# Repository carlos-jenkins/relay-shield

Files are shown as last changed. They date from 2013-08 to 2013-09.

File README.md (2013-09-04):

Advanced Relay Shield for Spark Core
====================================

[Spark Core] [] is a open source hardware Arduino compatible tiny Wi-Fi
development board that makes it easy to create internet-connected hardware.
This shield allows the Spark Core to control a high-power AC device and sense
the current flow.

Features
--------

  - Rated up to 220VAC @ 20A (4400W) ([part] [1]).
  - Current sensing using a CT sensor ([part] [2]).
  - Manual switch.
  - Panel/box ready.

Schematic
---------

Schematic

[Schematic in PDF] [].

PCB
---

PCB

[PCB on OSHPark] [].

License
-------

Copyright (C) 2013 Carlos Jenkins <carlos@jenkins.co.cr>

This program is free software; you can redistribute it and/or modify
it under the terms of the GNU General Public License as published by
the Free Software Foundation; either version 2 of the License, or
(at your option) any later version.

This program is distributed in the hope that it will be useful,
but WITHOUT ANY WARRANTY; without even the implied warranty of
MERCHANTABILITY or FITNESS FOR A PARTICULAR PURPOSE.  See the
GNU General Public License for more details.

You should have received a copy of the GNU General Public License
along with this program.  If not, see <http://www.gnu.org/licenses/>.

  [1]: https://www.sparkfun.com/products/10924
  [2]: https://www.sparkfun.com/products/11005
  [Spark Core]: https://www.sparkdevices.com/
  [Schematic in PDF]: https://github.com/carlos-jenkins/relay-shield/raw/master/board/schematic/v1.0/relay_shield.pdf
  [PCB on OSHPark]: http://oshpark.com/shared_projects/E1XSjK44

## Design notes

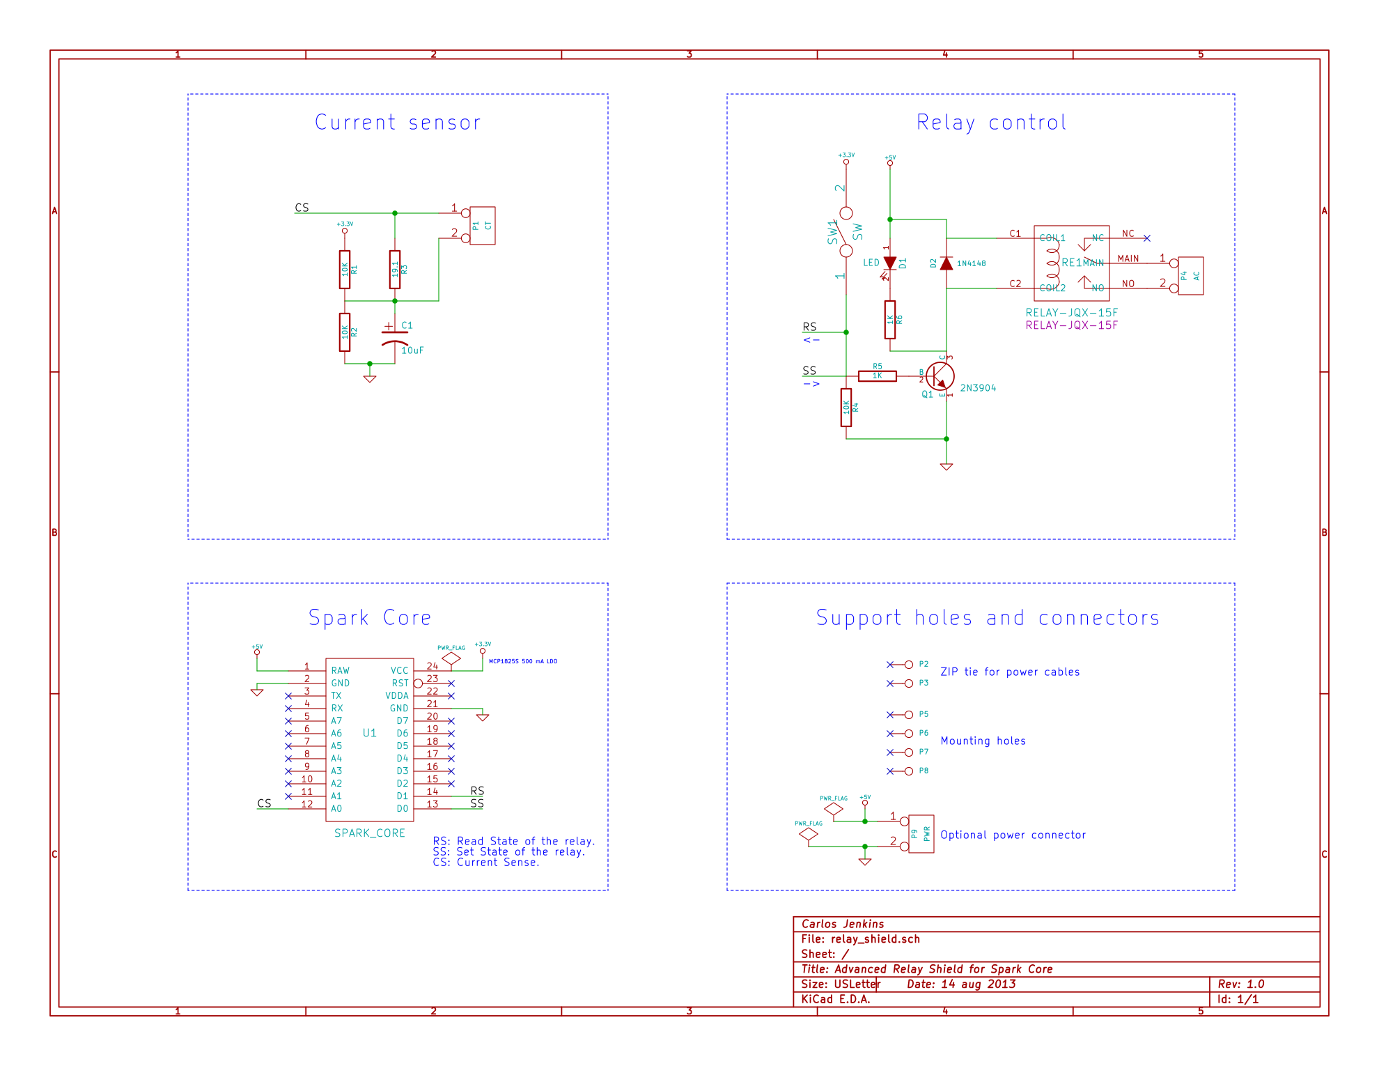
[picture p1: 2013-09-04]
board/schematic/v1.0/relay_shield.png

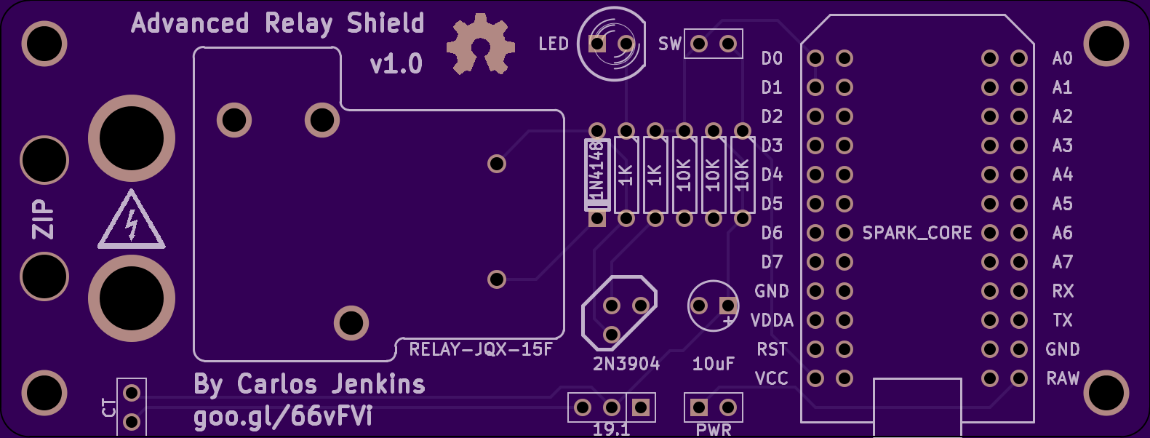
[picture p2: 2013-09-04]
board/pcb/v1.0/relay_shield.png

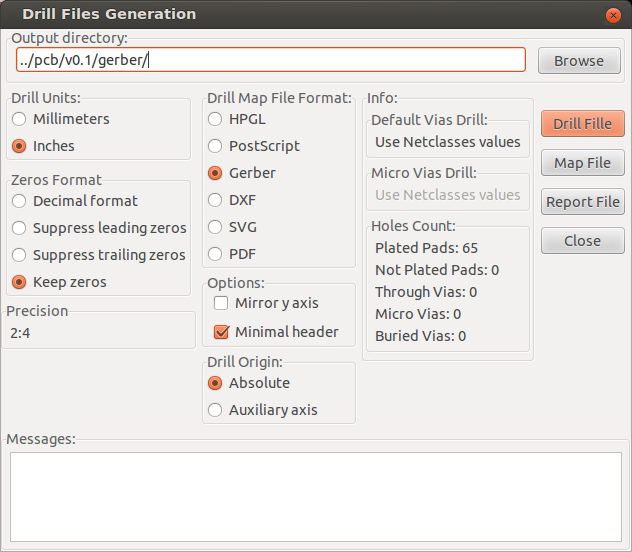
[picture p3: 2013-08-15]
board/pcb/oshpark_config_drill.png

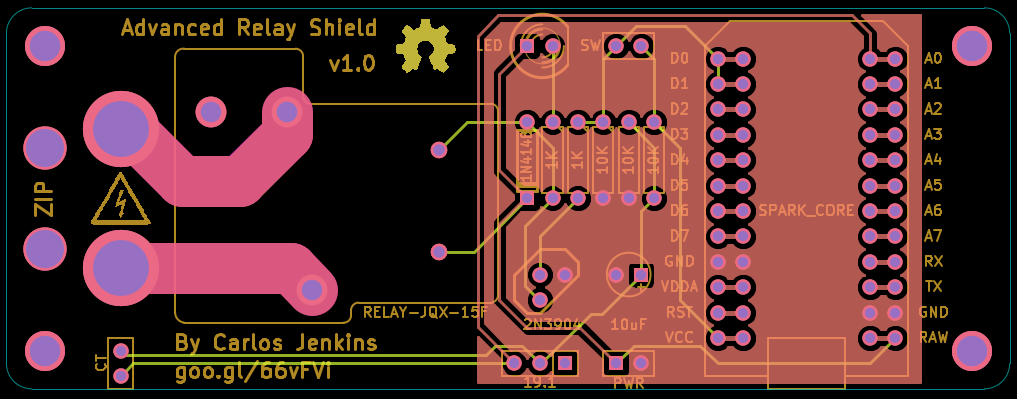
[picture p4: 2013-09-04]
board/pcb/v1.0/relay_shield (gerbv).png

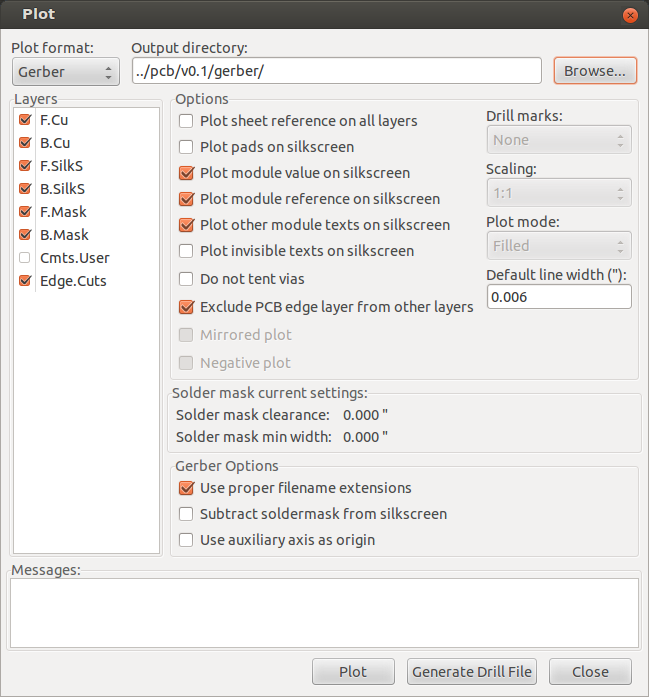
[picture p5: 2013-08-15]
board/pcb/oshpark_config_layers.png

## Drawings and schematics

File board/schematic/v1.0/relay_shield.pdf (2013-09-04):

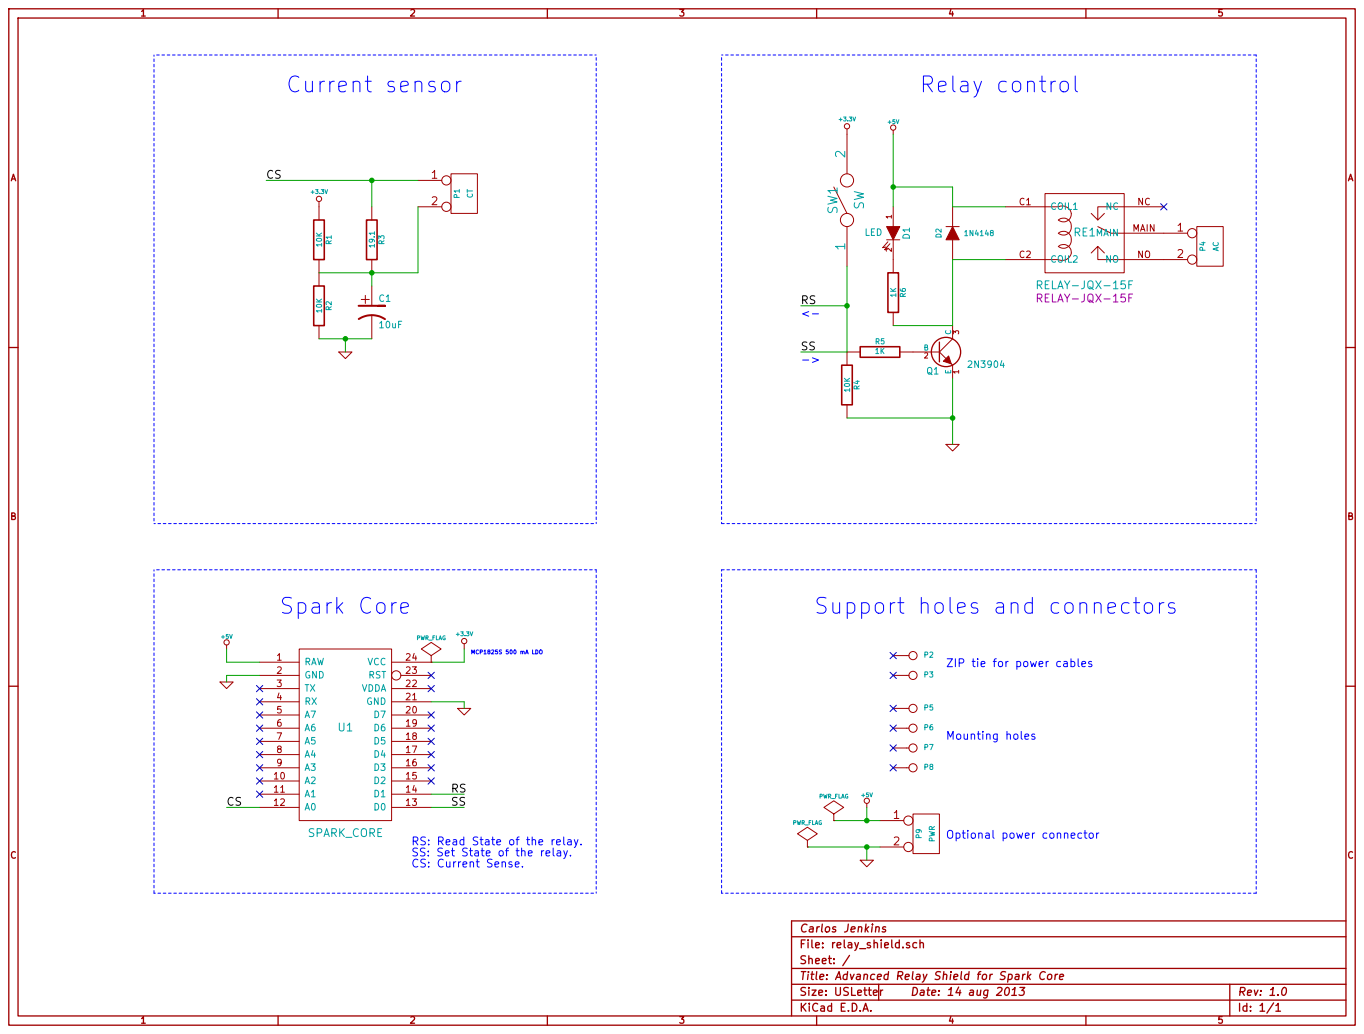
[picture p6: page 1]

RS: Read State of the relay.
SS: Set State of the relay.
CS: Current Sense.

File: relay_shield.sch
Sheet: /
Title: Advanced Relay Shield for Spark Core
KiCad E.D.A.

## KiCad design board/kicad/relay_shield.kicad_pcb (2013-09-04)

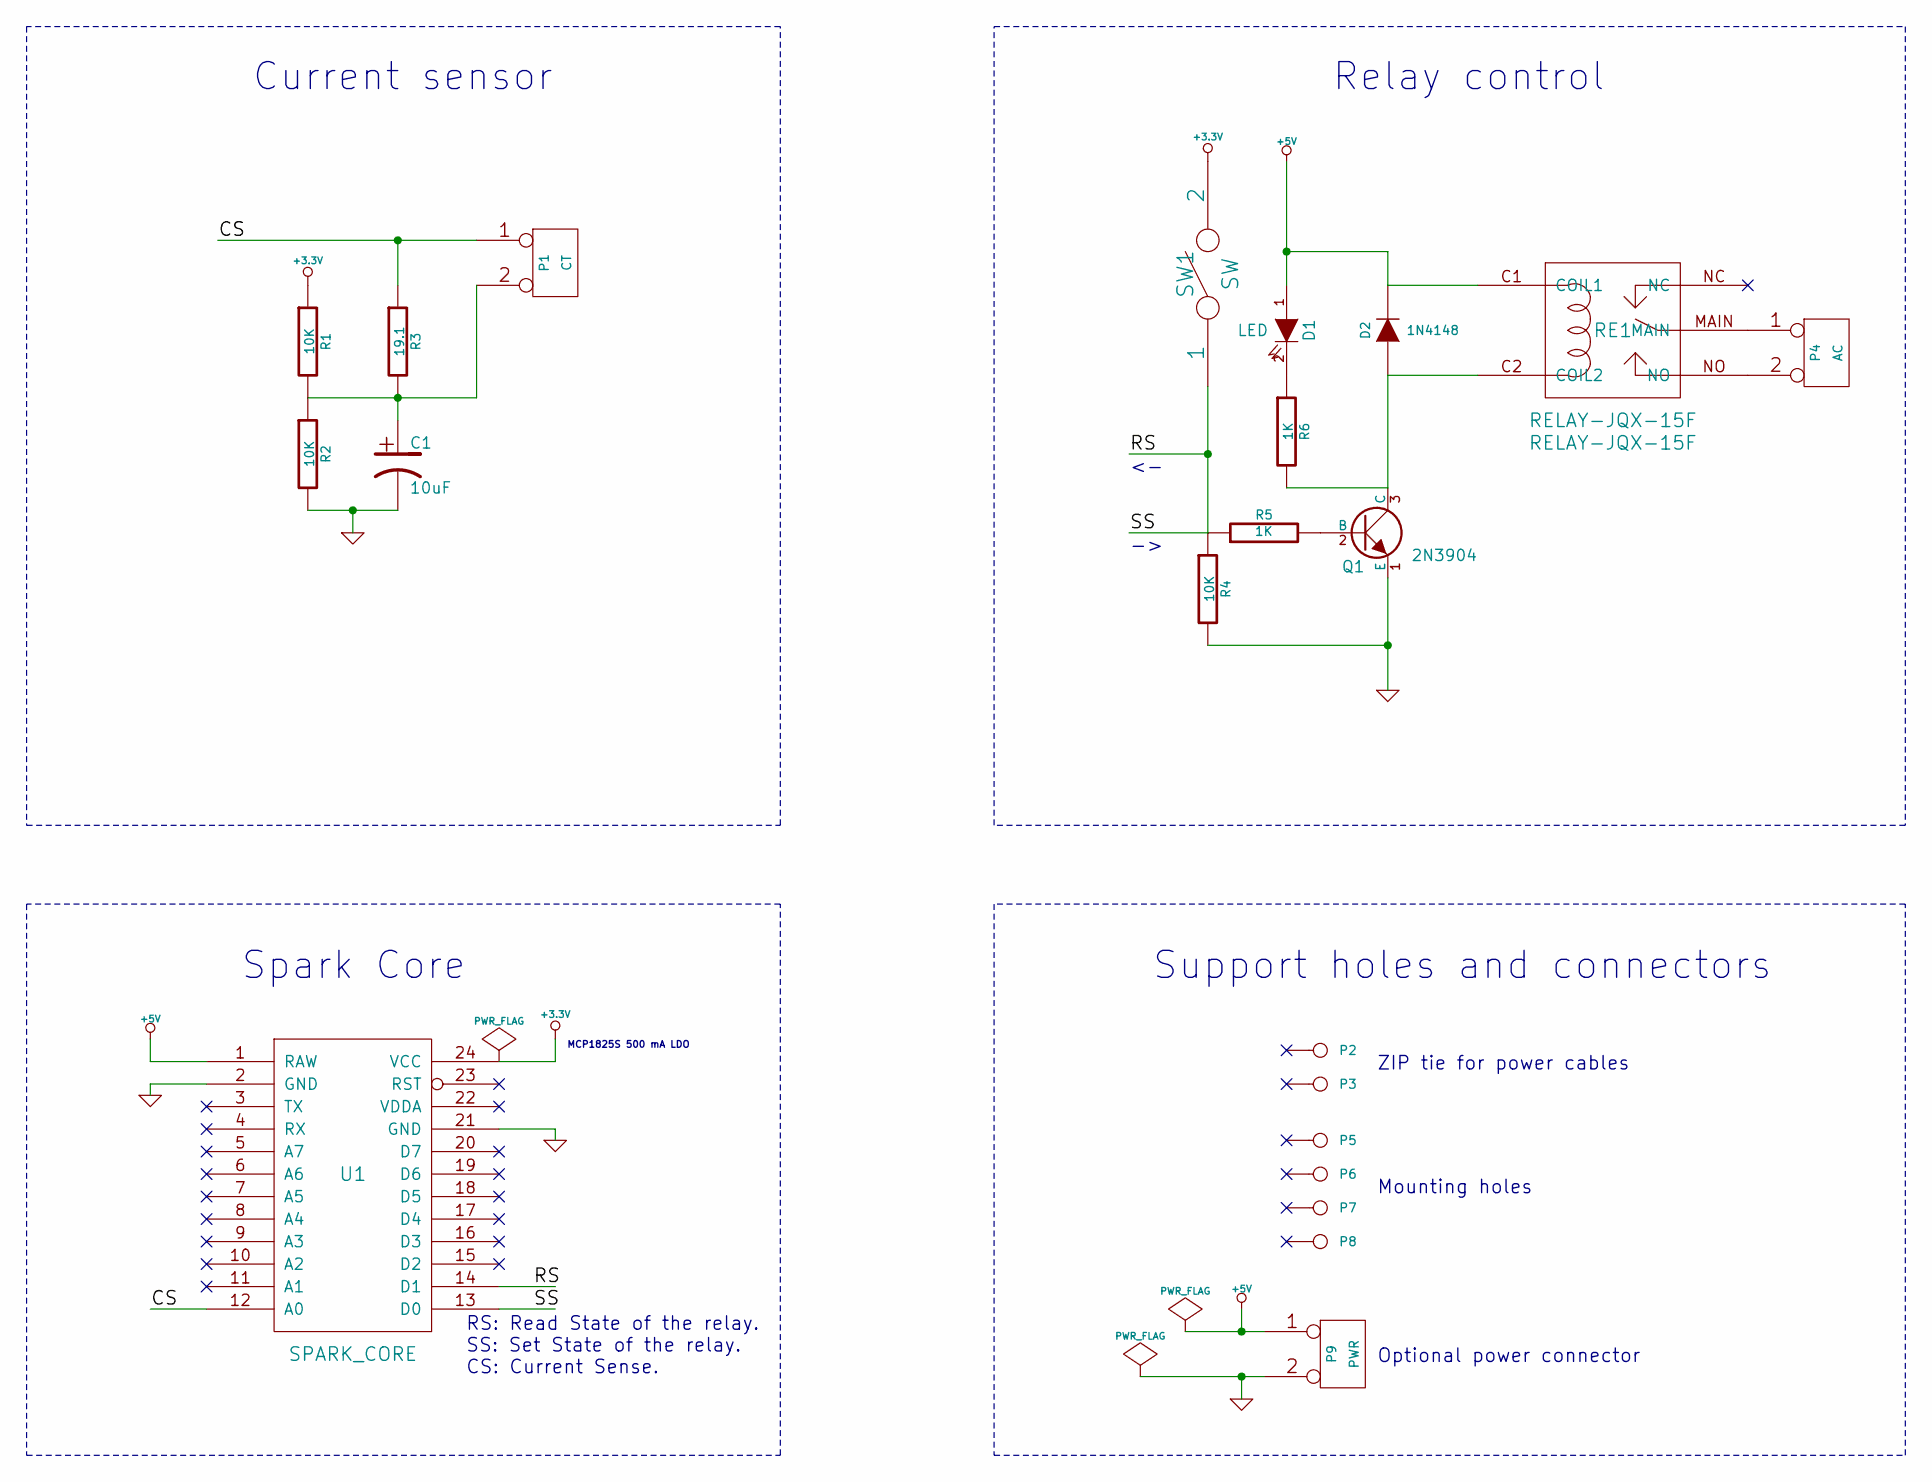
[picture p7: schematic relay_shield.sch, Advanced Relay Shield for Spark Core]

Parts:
C1: 10uF
D1: LED
D2: 1N4148
P1: CT
P2: Z1
P3: Z2
P4: AC
P5: MH1
P6: MH2
P7: MH3
P8: MH4
P9: PWR
Q1: 2N3904
R1, R2, R4: 10K
R3: 19.1
R5, R6: 1K
RE1: RELAY-JQX-15F
SW1: SW
U1: SPARK_CORE

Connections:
+3.3V: R1.1, SW1.2, U1.24 (VCC)
+5V: D1.1 (A), D2.2 (K), P9.1, RE1.C1 (COIL1), U1.1 (RAW)
/CS: P1.1, R3.1, U1.12 (A0)
/RS: R4.1, R5.1, SW1.1, U1.13 (D0), U1.14 (D1)
GND: C1.2, P9.2 (PM), Q1.1 (E), R2.2, R4.2, U1.2 (GND), U1.21 (GND)
unnamed: D2.1 (A), Q1.3 (C), R6.2, RE1.C2 (COIL2)
unnamed: C1.1, P1.2 (PM), R1.2, R2.1, R3.2
unnamed: P4.2 (PM), RE1.NO
unnamed: D1.2 (K), R6.1
unnamed: Q1.2 (B), R5.2
unnamed: P4.1, RE1.MAIN

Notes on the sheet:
RS: Read State of the relay. SS: Set State of the relay. CS: Current Sense.
MCP1825S 500 mA LDO
ZIP tie for power cables
Mounting holes
Support holes and connectors
Spark Core
Current sensor
Relay control
Optional power connector

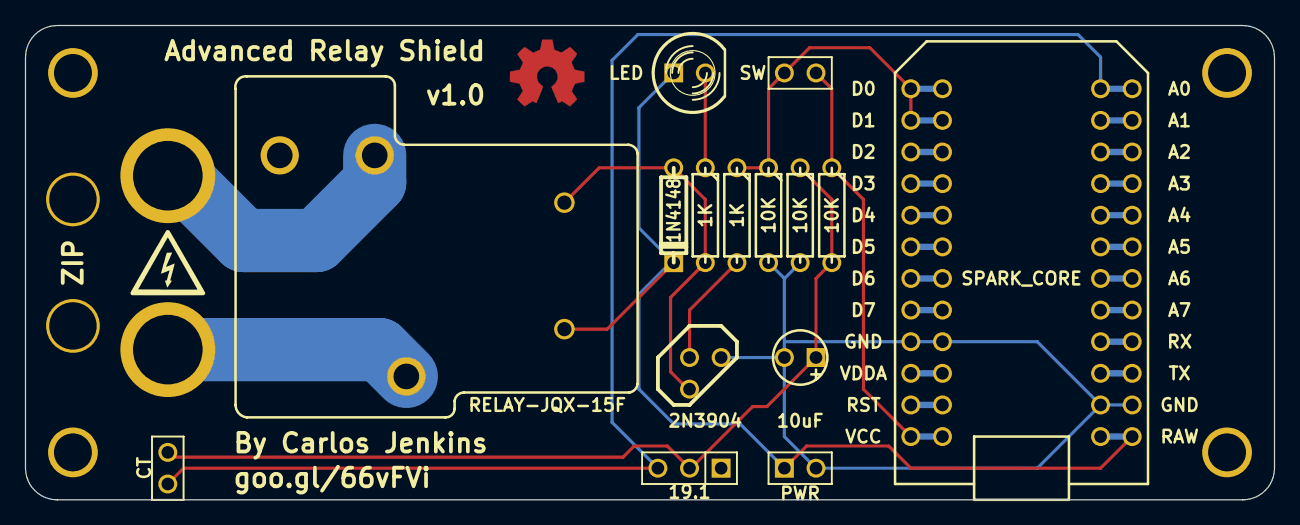
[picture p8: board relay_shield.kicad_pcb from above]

Board: 2 copper layers, 100.3 x 38.1 mm, 25 parts (0 on the bottom side), 11 nets.

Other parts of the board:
OSHW: oshw_logo
OSHW_M: oshw_logo
WARN: high_voltage_logo

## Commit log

2013-08-13 Added base KiCad project.
    [relay_shield.sch]
2013-08-13 Added Spark Core library/component.
    [relay_shield.sch]
2013-08-14 Optoisolator version. Not sure if to follow that path.
    [relay_shield.sch]
2013-08-14 Changed repository layout and added converted Eagle files.
    [relay_shield.sch]
2013-08-14 Finished schematic version 0.1.
    [relay_shield.sch]
2013-08-14 Forgot to add a connector for power.
    [relay_shield.sch]
2013-08-14 Base layout of the PCB.
    [relay_shield.kicad_pcb, relay_shield.sch]
2013-08-15 Finished to route the board.
    [relay_shield.kicad_pcb]
2013-08-15 Normalized folders for version 0.1 and fixed some errors on Silkscreen.
    [relay_shield.kicad_pcb]
2013-08-15 Fixed URL of the schematic image.
2013-08-15 Finished the Silkscreen.
    [relay_shield.kicad_pcb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]
2013-08-15 Added a PNG version of the gerbers.
    [relay_shield-B_Cu.gbl, relay_shield-B_Mask.gbs, relay_shield-B_SilkS.gbo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]
2013-08-15 Added PCB to README.md.
    [relay_shield.kicad_pcb]
2013-08-15 Almost final gerbers for production.
    [relay_shield-B_Cu.gbl, relay_shield-B_Mask.gbs, relay_shield-B_SilkS.gbo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]
2013-09-04 Added extra pads to allow connection to unused pins. Also fixed stand-offs size.
    [relay_shield.kicad_pcb]
2013-09-04 Rolled out v1.0.
    [relay_shield-B_Cu.gbl, relay_shield-B_Mask.gbs, relay_shield-B_SilkS.gbo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]
